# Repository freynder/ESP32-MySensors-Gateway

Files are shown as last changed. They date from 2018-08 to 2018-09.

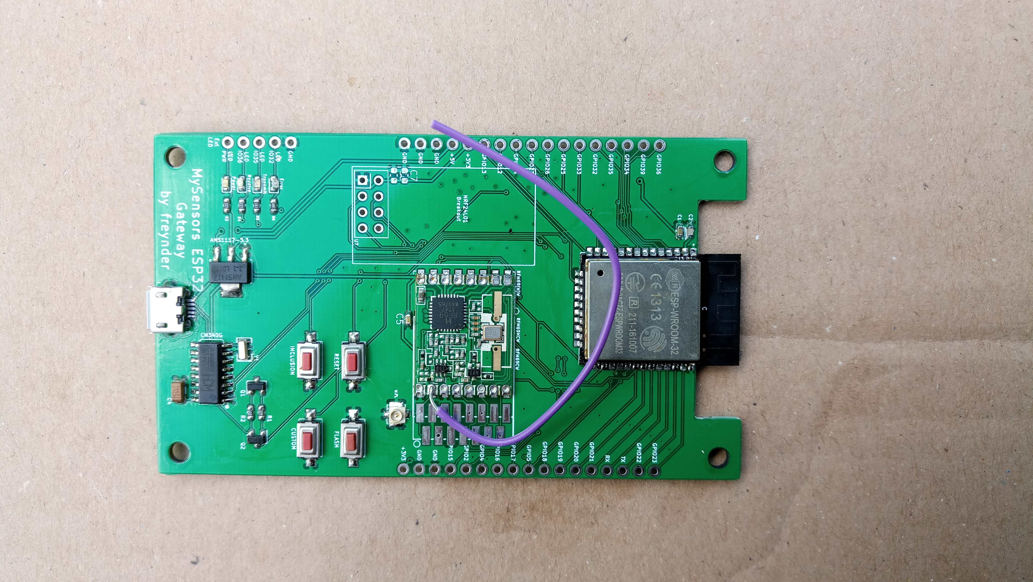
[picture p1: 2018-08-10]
soldered.jpg

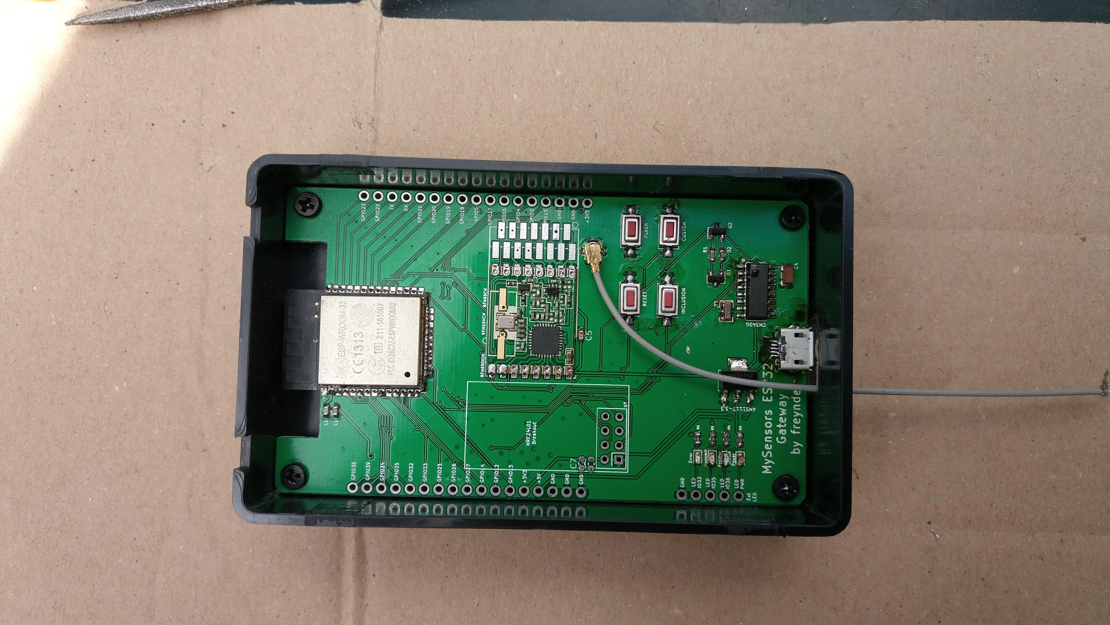
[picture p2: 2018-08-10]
boxed.jpg

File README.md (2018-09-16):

An ESP32 board designed to function as a Mysensors Gateway with the following features:

- Designed to fit in a cheap enclosure available from AliExpress such as [this](https://www.aliexpress.com/item/100x60x25mm-ABS-DIY-Plastic-Electronic-Project-Box-Enclosure-Instrument/32816989679.html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,searchweb201602_3_10152_10151_10065_10344_10068_10342_10325_10546_10343_10340_10548_10341_10696_10084_10083_10618_10304_10307_10820_10843_10059_100031_524_10103_10624_10623_10622_10621_10620,searchweb201603_6,ppcSwitch_5&algo_expid=a927ddcc-0543-4e6f-9c48-a30857222de3-2&algo_pvid=a927ddcc-0543-4e6f-9c48-a30857222de3&priceBeautifyAB=0)
- Footprints for RFM69 and nRF24L01 breakout boards
- uFL antenna connector for RFM69.
- Optional onboard LEDs for POWER, ERROR, TX, RX, Inclusion. Header for external LEDs if desired.
- Breakout header for I2C boards such as Si7021, HTU21D, SHTT71 and BME280 sensors.
- Breakout header for RXB6 433Mhz RF receiver
- Inclusion button and general purpose custom button. Header for external buttons if desired.
- Powered and programmed over USB. Auto-reset and flash mechanism.
- Dual regulator: RF modules have a dedicated power regulator to improve reliability.
- All parts can be sourced from AliExpress. See the BOM for links.

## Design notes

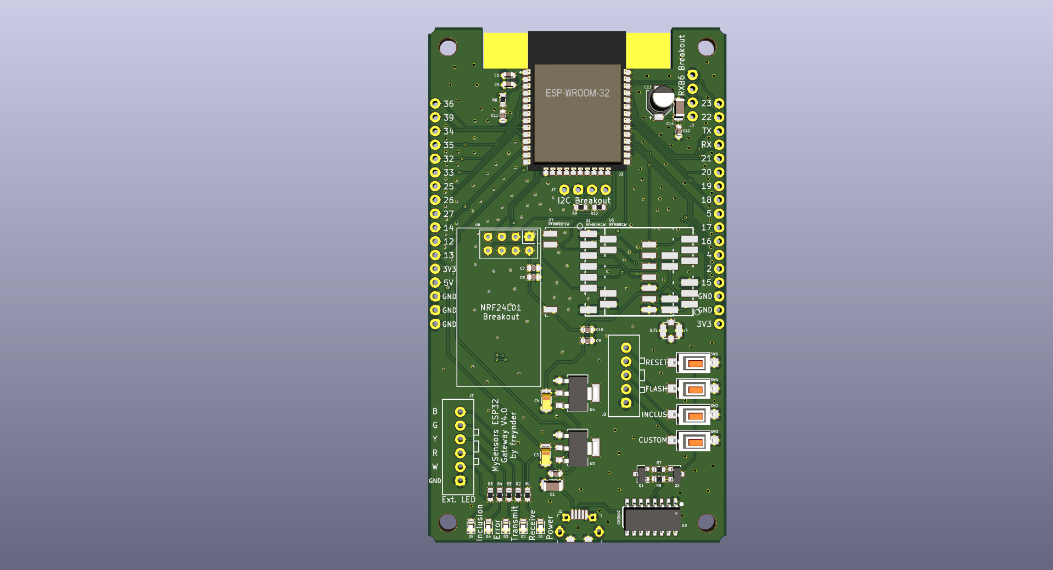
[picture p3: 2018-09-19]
top.png

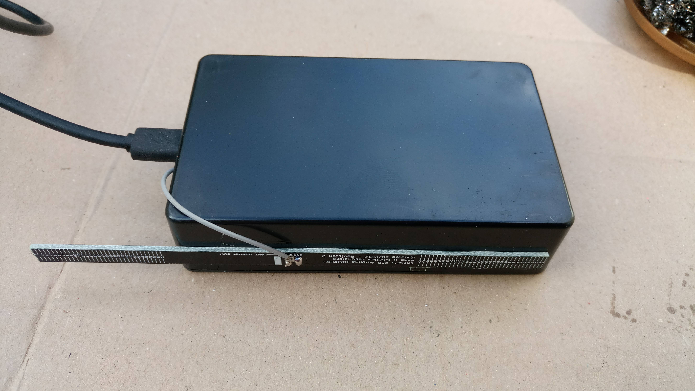
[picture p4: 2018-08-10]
closed_box.jpg

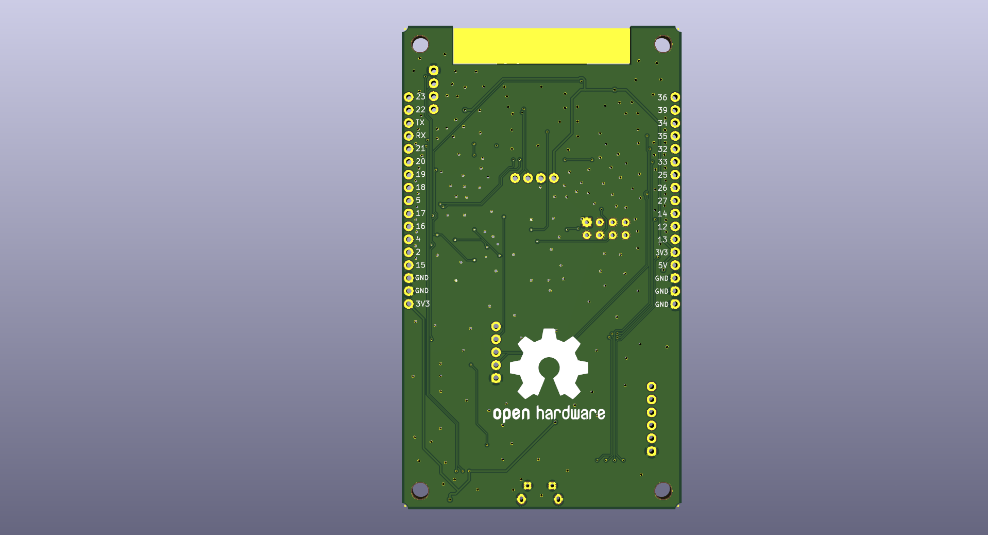
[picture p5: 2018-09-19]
bottom.png

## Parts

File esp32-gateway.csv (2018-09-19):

Id | Designator | Package | Quantity | Designation | Supplier and ref
1 | R10,R9 | R_0603_1608Metric | 2 | 4.7K
2 | C13 | CP_Elec_4x5.4 | 1 | 0.47uF
3 | J8 | 1X04_NO_SILK | 1 | RXB6 Breakout
4 | C12 | C_1206_3216Metric | 1 | 10uF
5 | C2,C14,C9,C11,C5 | C_0603_1608Metric | 5 | 0.1uF
6 | C1 | C_1206_3216Metric | 1 | 4.7uF
7 | J7 | 1X04_NO_SILK | 1 | I2C Breakout
8 | J2 | connector-XH2.54-01x05 | 1 | Button Connector
9 | J3 | connector-XH2.54-01x06 | 1 | Ext LED header
10 | U2 | MODULE_ESP-WROOM-32 | 1 | ESP-WROOM-32
11 | U6 | nRF24L01_Breakout | 1 | NRF24L01_Breakout
12 | U7 | HOPERF_RFM69HW-MINPADS | 1 | RFM69(H)W
13 | U5 | RFM69CW-XXXS2-MINPADS | 1 | RFM69CW
14 | U1 | RFM69HCW-XXXS2-MINPADS | 1 | RFM69HCW
15 | U4,U3 | AMS1117-3.3 | 2 | AMS1117-3.3
16 | C10,C6 | C_0603_1608Metric | 2 | 10uF
17 | C4,C3 | C_1206_3216Metric | 2 | 22uF
18 | R5,R1,R2 | R_0603_1608Metric | 3 | 22
19 | R6 | R_0603_1608Metric | 1 | 10K
20 | R3,R4 | R_0603_1608Metric | 2 | 120
21 | R7,R8 | R_0603_1608Metric | 2 | 12K
22 | D4 | LED_0603_1608Metric | 1 | LED RED
23 | D3 | LED_0603_1608Metric | 1 | LED YELLOW
24 | D2 | LED_0603_1608Metric | 1 | LED GREEN
25 | D1 | LED_0603_1608Metric | 1 | LED BLUE
26 | D5 | LED_0603_1608Metric | 1 | LED WHITE
27 | C7 | C_0603_1608Metric | 1 | 10nF
28 | C8 | C_0603_1608Metric | 1 | 1nF
29 | SW2 | SW_SPST_CK_RS282G05A3 | 1 | SW_INCLUSION
30 | SW3 | SW_SPST_CK_RS282G05A3 | 1 | SW_GEN1
31 | J6 | 1X17_NO_SILK | 1 | Header Right
32 | J5 | 1X17_NO_SILK | 1 | Header Left
33 | MK3,MK2,MK1,MK4 | MountingHole_3.2mm_M3 | 4 | Mounting_Hole
34 | J1 | aliexpress_micro_USB_connector | 1 | USB_B_Micro
35 | J4 | U.FL_Molex_MCRF_73412-0110_Vertical | 1 | u.FL
36 | SW1 | SW_SPST_CK_RS282G05A3 | 1 | SW_RESET
37 | SW4 | SW_SPST_CK_RS282G05A3 | 1 | SW_BOOT
38 | U8 | SO16 | 1 | CH340C
39 | Q1,Q2 | SOT-23 | 2 | Q_NPN_BEC
40 | REF** | OSHW-Logo2_24.3x20mm_SilkScreen | 1 | OSHW-Logo2_24.3x20mm_SilkScreen

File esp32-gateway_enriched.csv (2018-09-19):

Designator | Package | Quantity | Designation | Supplier and ref
C1 | C_1206_3216Metric | 1 | 4.7uF | any
C10,C6 | C_0603_1608Metric | 2 | 10uF | any
C12 | C_1206_3216Metric | 1 | 10uF | any
C13 | CP_Elec_4x5.4 | 1 | 0.47uF | any
C2,C14,C9,C11,C5 | C_0603_1608Metric | 5 | 0.1uF | any
C4,C3 | C_1206_3216Metric | 2 | 22uF | any
C7 | C_0603_1608Metric | 1 | 10nF | any
C8 | C_0603_1608Metric | 1 | 1nF | any
D1 | LED_0603_1608Metric | 1 | LED BLUE | https://www.aliexpress.com/item/5-x-100pcs-Color-500pcs-New-1206-0805-0603-Red-Green-Blue-White-Yellow-SMD-LED/837971310.html
D2 | LED_0603_1608Metric | 1 | LED GREEN | https://www.aliexpress.com/item/5-x-100pcs-Color-500pcs-New-1206-0805-0603-Red-Green-Blue-White-Yellow-SMD-LED/837971310.html
D3 | LED_0603_1608Metric | 1 | LED YELLOW | https://www.aliexpress.com/item/5-x-100pcs-Color-500pcs-New-1206-0805-0603-Red-Green-Blue-White-Yellow-SMD-LED/837971310.html
D4 | LED_0603_1608Metric | 1 | LED RED | https://www.aliexpress.com/item/5-x-100pcs-Color-500pcs-New-1206-0805-0603-Red-Green-Blue-White-Yellow-SMD-LED/837971310.html
D5 | LED_0603_1608Metric | 1 | LED WHITE | https://www.aliexpress.com/item/5-x-100pcs-Color-500pcs-New-1206-0805-0603-Red-Green-Blue-White-Yellow-SMD-LED/837971310.html
J1 | aliexpress_micro_USB_connector | 1 | USB_B_Micro | https://www.aliexpress.com/item/100pcs-Micro-Jack-Connector-Female-5pin-Charging-Socket-Micro-USB-5Pin-Inserting-Plate-Seat-Mini-usb/32834165597.html
J2 | connector-XH2.54-01x05 | 1 | Button Connector | https://www.aliexpress.com/item/50PCS-Lot-XH2-54-Pin-Header-Connector-2P-3P-4P-5P-6P-7P-8P-9P-10P/32820868041.html
J3 | connector-XH2.54-01x06 | 1 | Ext LED header | https://www.aliexpress.com/item/50PCS-Lot-XH2-54-Pin-Header-Connector-2P-3P-4P-5P-6P-7P-8P-9P-10P/32820868041.html
J4 | U.FL_Molex_MCRF_73412-0110_Vertical | 1 | u.FL | https://www.aliexpress.com/item/Free-Shipping-50PCS-U-FL-R-SMT-U-FL-socket-IPEX-IPX-connectors-RF-Coaxial-Connector/32872904554.html
J5 | 1X17_NO_SILK | 1 | Header Left | standard pin header
J6 | 1X17_NO_SILK | 1 | Header Right | standard pin header
J7 | 1X04_NO_SILK | 1 | I2C Breakout | standard pin header
J8 | 1X04_NO_SILK | 1 | RXB6 Breakout | standard pin header
Q1,Q2 | SOT-23 | 2 | Q_NPN_BEC | https://www.aliexpress.com/item/20PCS-Lot-New-Original-J3Y-S8050-SMD-SOT-23-Triode-Wholesale-Electronic/32495368656.html
R10,R9 | R_0603_1608Metric | 2 | 4.7K | any
R3,R4 | R_0603_1608Metric | 2 | 120 | any
R5,R1,R2 | R_0603_1608Metric | 3 | 22 | any
R6 | R_0603_1608Metric | 1 | 10K | any
R7,R8 | R_0603_1608Metric | 2 | 12K | any
SW1 | SW_SPST_CK_RS282G05A3 | 1 | SW_RESET | https://www.aliexpress.com/item/100PCS-3X6X2-5mm-Tactile-Push-Button-Switch-Tact-Switch-Micro-Switch-2-Pin-SMD/32672806661.html
SW2 | SW_SPST_CK_RS282G05A3 | 1 | SW_INCLUSION | https://www.aliexpress.com/item/100PCS-3X6X2-5mm-Tactile-Push-Button-Switch-Tact-Switch-Micro-Switch-2-Pin-SMD/32672806661.html
SW3 | SW_SPST_CK_RS282G05A3 | 1 | SW_GEN1 | https://www.aliexpress.com/item/100PCS-3X6X2-5mm-Tactile-Push-Button-Switch-Tact-Switch-Micro-Switch-2-Pin-SMD/32672806661.html
SW4 | SW_SPST_CK_RS282G05A3 | 1 | SW_BOOT | https://www.aliexpress.com/item/100PCS-3X6X2-5mm-Tactile-Push-Button-Switch-Tact-Switch-Micro-Switch-2-Pin-SMD/32672806661.html
U1 | RFM69HCW-XXXS2-MINPADS | 1 | RFM69HCW | any
U2 | MODULE_ESP-WROOM-32 | 1 | ESP-WROOM-32 | any
U4,U3 | AMS1117-3.3 | 2 | AMS1117-3.3 | https://www.aliexpress.com/item/100PCS-LOT-Original-AMS1117-3-3-AMS1117-3-3V-AMS1117-LM1117-1117-Voltage-Regulator-We-only/32816744520.html
U5 | RFM69CW-XXXS2-MINPADS | 1 | RFM69CW | any
U6 | nRF24L01_Breakout | 1 | NRF24L01_Breakout | https://www.aliexpress.com/item/E01-ML01D-small-size-SPI-nRF24L01P-2-4Ghz-1mW-PCB-antenna-IOT-uhf-wireless-transceiver-transmitter/32803704874.html
U7 | HOPERF_RFM69HW-MINPADS | 1 | RFM69(H)W | any
U8 | SO16 | 1 | CH340C | https://www.aliexpress.com/item/10pcs-340-C-With-C-100-New-CH340C-USB-To-Serial-Chip-Chip-SOP-16/32880586760.html

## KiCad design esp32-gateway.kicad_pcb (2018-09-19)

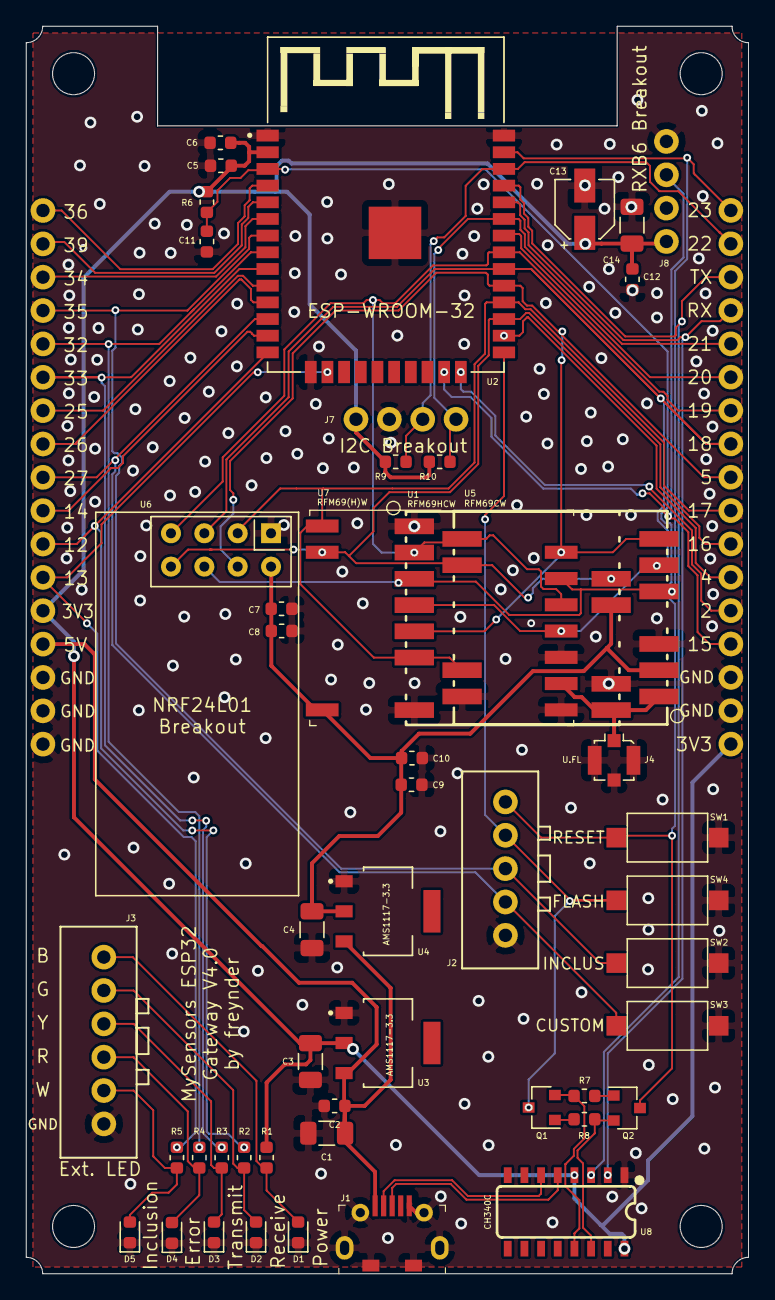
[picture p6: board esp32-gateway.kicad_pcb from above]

Board: 2 copper layers, 55.0 x 95.0 mm, 55 parts (0 on the bottom side), 44 nets.

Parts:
C1: 4.7uF; C_1206_3216Metric
C2, C5, C9, C11, C14: 0.1uF; C_0603_1608Metric
C3, C4: 22uF; C_1206_3216Metric
C6, C10: 10uF; C_0603_1608Metric
C7: 10nF; C_0603_1608Metric
C8: 1nF; C_0603_1608Metric
C12: 10uF; C_1206_3216Metric
C13: 0.47uF; CP_Elec_4x5.4
D1: LED BLUE; LED_0603_1608Metric
D2: LED GREEN; LED_0603_1608Metric
D3: LED YELLOW; LED_0603_1608Metric
D4: LED RED; LED_0603_1608Metric
D5: LED WHITE; LED_0603_1608Metric
J1: USB_B_Micro; aliexpress_micro_USB_connector
J2: Button Connector; connector-XH2.54-01x05
J3: Ext LED header; connector-XH2.54-01x06
J4: u.FL; U.FL_Molex_MCRF_73412-0110_Vertical
J5: Header Left; 1X17_NO_SILK
J6: Header Right; 1X17_NO_SILK
J7: I2C Breakout; 1X04_NO_SILK
J8: RXB6 Breakout; 1X04_NO_SILK
MK1, MK2, MK3, MK4: Mounting_Hole; MountingHole_3.2mm_M3
Q1, Q2: Q_NPN_BEC; SOT-23
R1, R2, R5: 22; R_0603_1608Metric
R3, R4: 120; R_0603_1608Metric
R6: 10K; R_0603_1608Metric
R7, R8: 12K; R_0603_1608Metric
R9, R10: 4.7K; R_0603_1608Metric
SW1: SW_RESET; SW_SPST_CK_RS282G05A3
SW2: SW_INCLUSION; SW_SPST_CK_RS282G05A3
SW3: SW_GEN1; SW_SPST_CK_RS282G05A3
SW4: SW_BOOT; SW_SPST_CK_RS282G05A3
U1: RFM69HCW; RFM69HCW-XXXS2-MINPADS
U2: ESP-WROOM-32; MODULE_ESP-WROOM-32
U3, U4: AMS1117-3.3
U5: RFM69CW; RFM69CW-XXXS2-MINPADS
U6: NRF24L01_Breakout; nRF24L01_Breakout
U7: RFM69(H)W; HOPERF_RFM69HW-MINPADS
U8: CH340C; SO16

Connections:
+5V: C1.1, C2.1, J1.1, J5.14, U3.3, U4.3
CE-RST: J6.8, U1.6, U2.28, U5.13, U6.3, U7.1
D+: J1.3, U8.5
D-: J1.2, U8.6
DTR: Q1.2, R7.2, U8.13
EN: C11.2, J2.1, Q2.3, R6.2, SW1.1, U2.3
ESPRX: J6.14, U2.34, U8.2
ESPTX: J6.15, U2.35, U8.3
GND: C1.2, C2.2, C3.2, C4.2, C5.2, C6.2, C7.1, C8.1, C9.1, C10.1, C11.1, C12.2, C13.2, C14.2, D1.1, D2.1, D3.1, D4.1, D5.1, J1.5, J1.6, J2.5, J3.6, J4.2, J5.15, J5.16, J5.17, J6.2, J6.3, J7.2, J8.4, SW1.2, SW2.2, SW3.2, SW4.2, U1.1, U1.8, U1.10, U2.1, U2.1.1, U2.15, U2.38, U3.1, U4.1, U5.3, U5.14, U6.1, U7.9, U7.11, U8.1
IO0: J2.2, Q1.3, SW4.1, U2.25
IO2: J6.5, U2.24
IO4: J6.6, U2.26
IO5: J6.9, U1.5, U2.29, U5.7, U6.4, U7.15
IO12: J5.11, R2.2, U2.14
IO13: J5.12, R5.2, U2.16
IO14: J5.10, U2.13
IO15: J6.4, J8.3, U2.23
IO16: J6.7, U1.14, U2.27, U5.9, U6.8, U7.2
IO18: J6.10, U1.4, U2.30, U5.6, U6.5, U7.12
IO19: J6.11, U1.2, U2.31, U5.8, U6.7, U7.13
IO20: J6.12, U2.32
IO21: J6.13, J7.4, R10.1, U2.33
IO22: J6.16, J7.3, R9.1, U2.36
IO23: J6.17, U1.3, U2.37, U5.5, U6.6, U7.14
IO25: J5.7, U2.10
IO26: J5.8, U2.11
IO27: J2.4, J5.9, SW3.1, U2.12
IO32: J5.5, R4.2, U2.8
IO33: J5.6, R3.2, U2.9
IO34: J5.3, U2.6
IO35: J2.3, J5.4, SW2.1, U2.7
LEDB: C3.1, C5.1, C6.1, C12.1, C13.1, C14.1, J5.13, J6.1, J7.1, J8.1, R1.2, R6.1, R9.2, R10.2, U2.2, U3.2, U8.4, U8.16
unnamed: D1.2, J3.1, R1.1
unnamed: D2.2, J3.2, R2.1
unnamed: D3.2, J3.3, R3.1
unnamed: D4.2, J3.4, R4.1
unnamed: D5.2, J3.5, R5.1
unnamed: Q1.1, R8.2
unnamed: Q2.1, R7.1
RFMANT: J4.1, U1.9, U5.1, U7.10
RFPOW: C4.1, C7.2, C8.2, C9.2, C10.2, U1.13, U4.2, U5.2, U6.2, U7.8
RTS: Q2.2, R8.1, U8.14
SENSOR_VN: J5.2, U2.5
SENSOR_VP: J5.1, U2.4

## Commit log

2018-07-07 Added readme, optimized traces, added decoupling capacitors
    [esp32-gateway-B.Cu.gbl, esp32-gateway-B.Cu.gbr, esp32-gateway-B.Mask.gbr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]
2018-07-07 Some small trace optimizations
    [esp32-gateway-B.Cu.gbl, esp32-gateway-B.Cu.gbr, esp32-gateway-B.Mask.gbr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]
2018-08-13 Fixed initial issues and made font larger.
    Issues fixed are:
    - TX and RX LEDs connected to IO34 and IO35 do not work as ESP32 does not support pull-up on those pins.
    - Wrong labeling of RX led (mentioned 36 but should be 34)
    - C4 capacitor was located near the CH340G chip but should have been near AMS1117
    - Missing pull-up on EN pin.
    - Missing capacitor to ground on EN pin.
    - auto flash does not work due to missing pull-up on EN pin.
    - corners need slight filing to fit in enclosure
    - moved usb connector a bit outside
    [esp32-gateway-B.Cu.gbl, esp32-gateway-B.Cu.gbr, esp32-gateway-B.Mask.gbr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]
2018-08-13 Add missing reference to silk screen (cosmetic)
    [esp32-gateway.kicad_pcb]
2018-08-19 Added dimensions
    [esp32-gateway.kicad_pcb]
2018-08-29 Corrected error and made nicer traces
    - inclusion button was connected to IO33, however IO33 was already in
    use for transmission led. Connected inclusion button to IO35 instead.
    - aligned traces better and maximized ground plane for a nicer board.
    [esp32-gateway-B.Cu.gbl, esp32-gateway-B.Cu.gbr, esp32-gateway-B.Mask.gbr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]
2018-09-04 Fixed design error for 3.3v power
    [esp32-gateway-B.Cu.gbl, esp32-gateway-B.Cu.gbr, esp32-gateway-B.Mask.gbr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]
2018-09-06 Apply net design rules
    [esp32-gateway-B.Cu.gbl, esp32-gateway-B.Cu.gbr, esp32-gateway-B.Mask.gbr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]
2018-09-15 Major redesign.
    - Changed headers to XH2.54 connectors for leds and buttons
    - Added secondary regulator to power RF modules
    - Changed RFM69 footprints to remove unused pads
    - Changed CHG340G chip to CHG340C, eliminating the crystal
    - Relayed all traces for cleaner design
    - Added capacitors at USB input power
    - Added second capacitor for decoupling at RFM69 modules
    [esp32-gateway.kicad_pcb, esp32-gateway.sch]
2018-09-15 git cleanup
    [esp32-gateway-B.Cu.gbl, esp32-gateway-B.Cu.gbr, esp32-gateway-B.Mask.gbr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]
2018-09-15 Silkscreen optimization plus BOM
    [esp32-gateway.csv, esp32-gateway.kicad_pcb, esp32-gateway_enriched.csv]
2018-09-15 Fixed power routing error
    [esp32-gateway.kicad_pcb]
2018-09-16 Added I2C breakout header
    [esp32-gateway.kicad_pcb, esp32-gateway.sch]
2018-09-16 Added Breakout for RXB6 433Mhz RF receiver
    [esp32-gateway.csv, esp32-gateway.kicad_pcb, esp32-gateway.sch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]
2018-09-19 Added pullup pins for I2C
    Please note that some breakout boards come with pullups included. It is
    advisable to desolder those or not include the pullup pins on the board.
    [esp32-gateway.csv, esp32-gateway.kicad_pcb, esp32-gateway.sch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]
